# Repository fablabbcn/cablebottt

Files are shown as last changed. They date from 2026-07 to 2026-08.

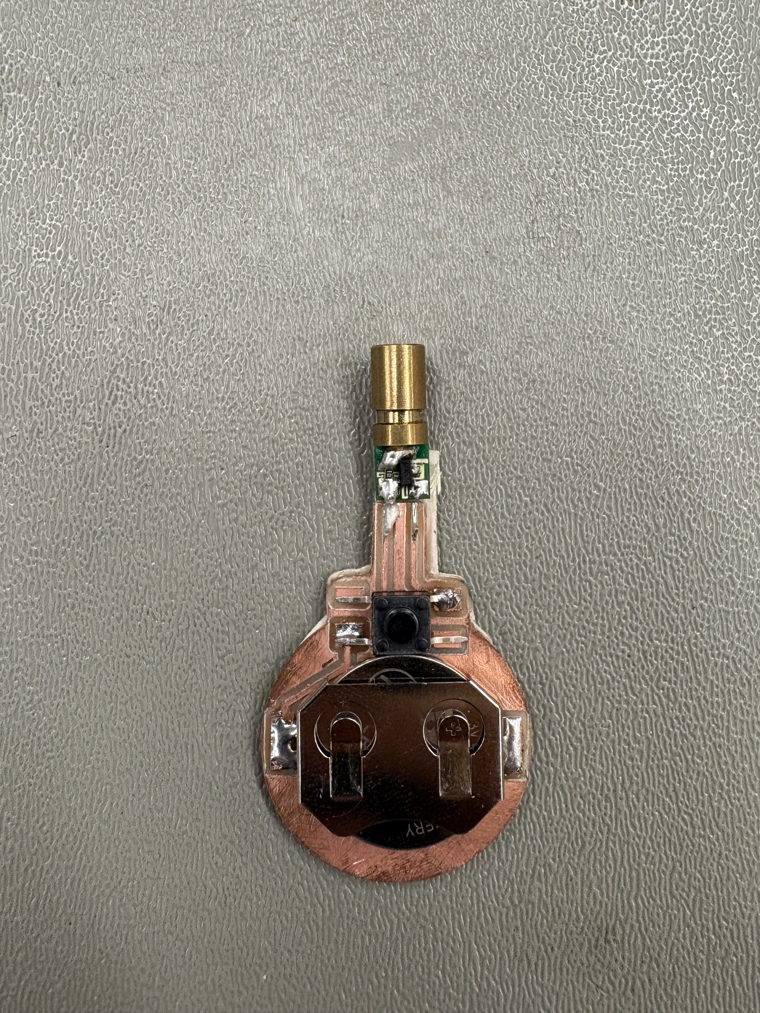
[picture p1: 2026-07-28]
images/puntero_02.jpg

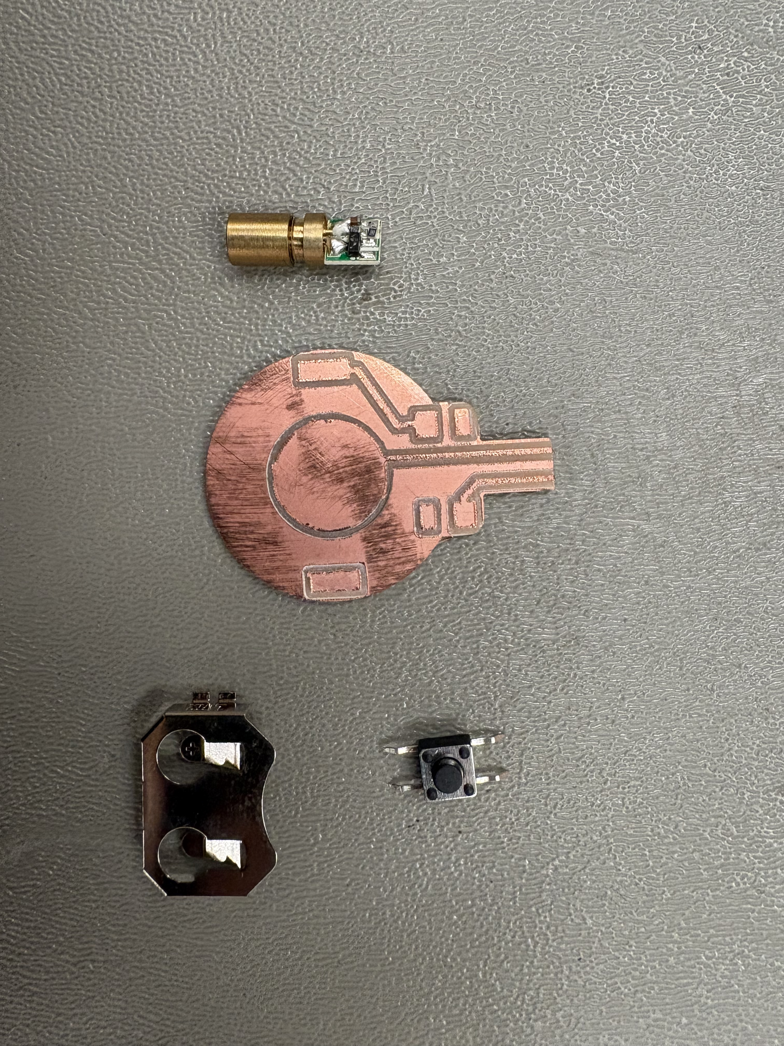
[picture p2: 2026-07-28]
images/puntero_01.jpg

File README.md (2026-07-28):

# CABLEBOTTT

**A hands-on STEAM workshop by FLU @ Fab Lab Barcelona.**

Design, fabricate and program a **cable-driven robot** (cablebot). Participants build a small robot that travels along a cable using a rotating motor, and bring it to life by wiring up inputs (light, distance) and outputs (motor, LED, buzzer, servo). The activity combines **mechanics + digital fabrication + computational thinking** in an accessible, creative format.

> Based on a yellow gearmotor driven from a **Seeed Studio XIAO ESP32-C3**, on a custom PCB.

---

## What you'll build

The cablebot comes in **two behaviors**, using the same hardware:

| | **Sketch A — autonomous** | **Sketch B — teleoperated** |
|---|---|---|
| **Idea** | The robot decides for itself | You drive it from your phone |
| **How** | Follows light using 2 LDR sensors | Serves a webapp over its own WiFi |
| **Inputs** | 2 light sensors (LDR) | Distance sensor (optional) |
| **Outputs** | Motor | Motor, color LED, buzzer, servo |
| **Libraries** | None | Adafruit NeoPixel + VL53L1X |
| **Best for** | Seeing a closed feedback loop | Programming your own behaviors |

Both are fully documented — see **[Programming](#3-programming)** below.

---

## Folder structure

```
cablebottt/
├── README.md                        ← you are here (project index)
│
├── fabrication/                     ← everything you cut / print / mill
│   ├── ⟨laser_pieces.svg⟩           ← laser-cut structure (the 3 assembly pieces)
│   ├── ⟨mount_3d.stl⟩               ← 3D-printed parts (if any)
│   ├── pcb/                         ← custom PCB (KiCad project + Gerbers)
│   │   ├── fab26_cablebot.kicad_pro
│   │   ├── fab26_cablebot.kicad_sch
│   │   ├── fab26_cablebot.kicad_pcb
│   │   ├── gerber/                  ← ready-to-mill / ready-to-order
│   │   └── svg/fab26_cablebot-preview.svg
│   └── silkscreen/back_silkscreen.svg
│
├── code/
│   ├── cablebottt_laser/cablebottt.ino        ← Sketch A (autonomous)
│   └── cablebottt_web/cablebottt_web.ino      ← Sketch B (teleoperated)
│
├── docs/
│   ├── cablebottt_sketch_A_tutorial.md        ← how to program Sketch A
│   └── cablebottt_sketch_B_tutorial.md        ← how to program Sketch B
│
└── images/                          ← photos & reference
    ├── ⟨assembled_bot.jpg⟩
    ├── ⟨soldering_xiao.jpg⟩
    └── ⟨pcb_render.png⟩
```

> **⟨…⟩ = placeholder.** Replace with your real filenames. If the layout above doesn't match how you organized the folder, adjust the paths — the section links below still work as long as the two `docs/…` tutorials keep their names.

---

## How to use this project

Do it in three stages. Each stage has its own detailed doc; this index just tells you the order.

### 1. Fabricate

| Part | File | Process |
|---|---|---|
| Structure | `fabrication/⟨laser_pieces.svg⟩` | Laser-cut, then assemble the 3 pieces |
| Custom PCB | `fabrication/pcb/gerber/` | Mill or order from the Gerbers |
| Board | Seeed Studio **XIAO ESP32-C3** | Solder the header pins onto the PCB |

Populate the PCB, solder the XIAO, attach the motor and the laser pointer, and assemble the laser-cut structure. Photos in **`images/`**.

### 2. Wire it up

The XIAO pinout, shared across both sketches:

| Function | Pin | Used by |
|---|---|---|
| Motor driver 1 / 2 | `D9` / `D10` | both |
| LDR left / right | `A1` / `A0` | Sketch A |
| NeoPixel (LED) | `D7` | Sketch B |
| Buzzer | `D6` | Sketch B |
| Servo | `D8` | Sketch B |
| Distance sensor SDA / SCL | `D4` / `D5` | Sketch B |

### 3. Programming

Pick the behavior and follow its step-by-step tutorial:

- **Autonomous (follows light)** → **[`docs/cablebottt_sketch_A_tutorial.md`](docs/cablebottt_sketch_A_tutorial.md)**
  *No libraries needed. Upload and go.*
- **Teleoperated (phone webapp)** → **[`docs/cablebottt_sketch_B_tutorial.md`](docs/cablebottt_sketch_B_tutorial.md)**
  *Install 2 libraries, then connect your phone to the `CABLEBOTTT` WiFi network.*

Both tutorials cover the one-time Arduino IDE + ESP32-C3 setup, so you only need to read it once.

---

## Quick start (already fabricated & flashed?)

1. Power the board over USB-C or the 9V battery.
2. **Sketch A:** shine a light near an LDR — the robot follows it.
3. **Sketch B:** on your phone, join WiFi **`CABLEBOTTT`** (password `cablebottt`), open **`http://192.168.4.1`**, and drive it.

---

*Originally created for a **FAB26 Boston** workshop. Repo: `github.com/fablabbcn/cablebottt`.*

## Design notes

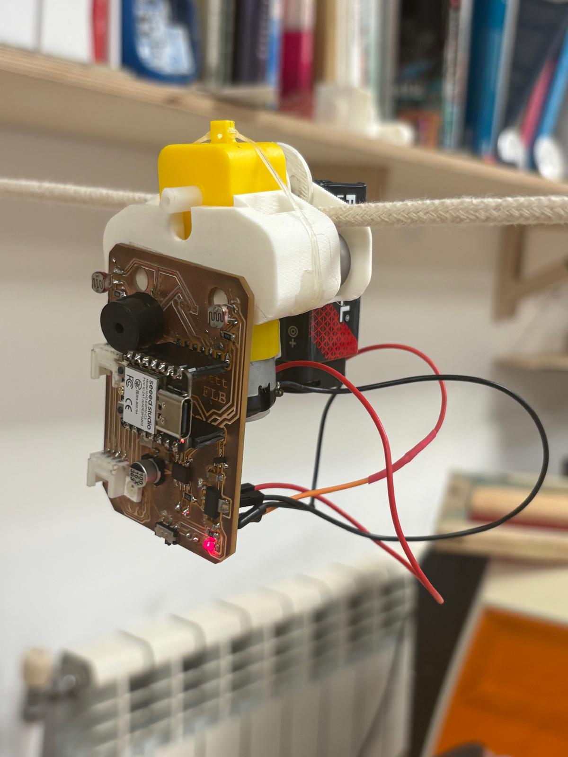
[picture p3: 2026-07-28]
images/Cable bot.jpeg

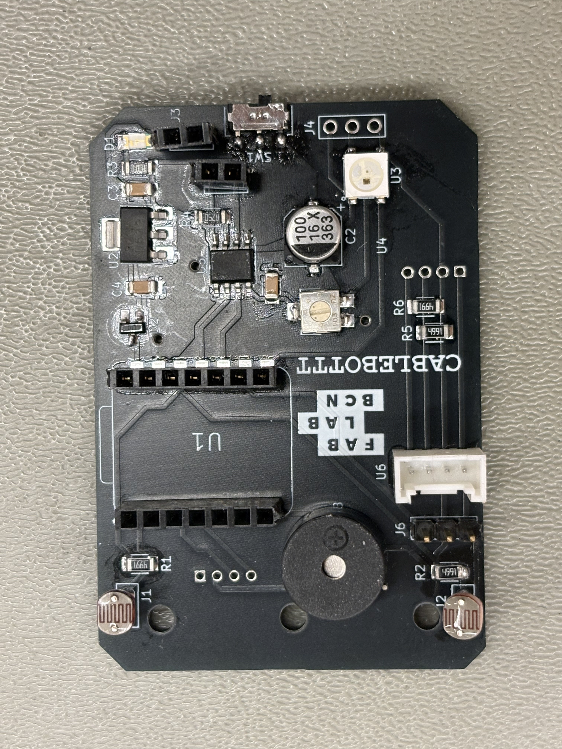
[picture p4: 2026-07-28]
images/board.jpg

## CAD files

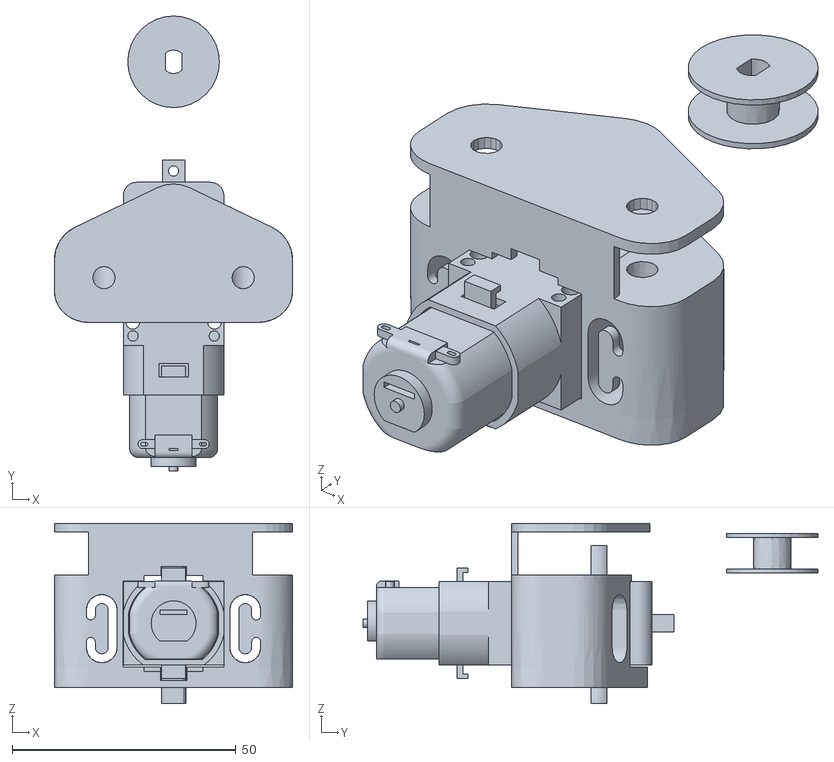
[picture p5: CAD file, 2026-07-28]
3d_design/rodamiento v3_R7.stl
53.2 x 101.6 x 40.2

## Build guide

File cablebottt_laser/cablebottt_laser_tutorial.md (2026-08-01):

# CABLEBOTTT — Sketch A: `cablebottt_laser`

**Autonomous light-following robot.** The cablebot reads two light-dependent resistors, or LDRs, and drives its motor towards the side receiving more light. It demonstrates a simple **sensor → decision → actuator** loop.

**Board:** Seeed Studio XIAO ESP32-C3
**File:** `cablebottt_laser/cablebottt.ino`
**Repository:** `github.com/fablabbcn/cablebottt`

---

## 📚 Libraries needed: none

This sketch does not use any external libraries. It relies only on functions included in the standard Arduino core for ESP32, including:

* `Serial`
* `analogRead`
* `analogWrite`
* `digitalWrite`
* `pinMode`
* `millis`
* `delay`

Once the ESP32 board package is installed, you can compile and upload the sketch directly. No additional installation through the Library Manager is required.

---

## Part 1 — One-time setup

You only need to complete this section once on each computer.

### 1.1 · Install the Arduino IDE

Download and install the stable version of **Arduino IDE 2.x** from:

`arduino.cc/en/software`

### 1.2 · Add ESP32 board support

1. Open **File › Preferences**. On macOS, open **Arduino IDE › Settings**.

2. Find **Additional Boards Manager URLs**.

3. Add:

   ```text
   https://espressif.github.io/arduino-esp32/package_esp32_index.json
   ```

4. Press **OK**.

### 1.3 · Install the ESP32 boards package

1. Open **Tools › Board › Boards Manager**, or select the boards icon in the left sidebar.
2. Search for `esp32`.
3. Install **esp32 by Espressif Systems**.

Installation may take a few minutes.

### 1.4 · Select the board and port

1. Connect the XIAO using a **USB-C data cable**. Some USB cables provide power but do not transfer data.
2. Select **Tools › Board › esp32 › XIAO_ESP32C3**.
3. Open **Tools › Port** and select the port that appears when the board is connected.

Typical port names are:

* Windows: `COM3`, `COM4`, etc.
* macOS: `/dev/cu.usbmodem…`
* Linux: `/dev/ttyACM0` or similar

### 1.5 · Enable USB serial output

Under **Tools**, set:

```text
USB CDC On Boot → Enabled
```

Without this setting, the Serial Monitor may remain blank when using the XIAO ESP32-C3 over USB-C.

Leave the other board options at their default values unless your setup requires otherwise.

---

## Part 2 — Upload Sketch A

### 2.1 · Open the sketch

Open:

```text
cablebottt_laser/cablebottt.ino
```

You can double-click the `.ino` file or use **File › Open** in the Arduino IDE.

### 2.2 · Check the board and port

Confirm that:

* the selected board is `XIAO_ESP32C3`;
* the correct serial port is selected.

### 2.3 · Upload

Press the **Upload** button.

The Arduino IDE will compile the sketch and write it to the board. A message such as:

```text
Hard resetting via RTS pin...
```

normally indicates that the upload completed successfully.

### 2.4 · Test the robot

1. Open **Tools › Serial Monitor**.
2. Set the baud rate to `115200`.
3. Restart the board.
4. Keep the laser or flashlight away from both sensors while the robot calibrates.
5. Shine light onto one LDR.

The motor should move towards the side receiving the stronger light.

Calibration takes approximately 1.5 seconds after startup. The robot should remain still during this period.

---

## How the sketch works

| Step | What happens |
| --- | --- |
| **Stabilise** | The sketch waits briefly after startup so the power supply and analogue readings can settle. |
| **Calibrate** | It averages 25 readings from each LDR to establish the ambient-light baseline. |
| **Read** | It continuously reads both sensors and calculates a moving average from the latest five samples. |
| **Measure change** | It compares each filtered reading with its startup baseline. In this circuit, more light produces a lower analogue value. |
| **Ignore noise** | Small changes are ignored using an activation threshold. Similar readings on both sides are ignored using a deadband. |
| **Decide** | The sketch identifies which LDR is receiving the stronger increase in light. |
| **Act** | It drives the motor towards that side. A larger difference between the sensors produces a higher motor speed. |
| **Stop** | The motor stops when there is no strong light signal or when both sensors receive similar amounts of light. |

This creates a basic **closed feedback loop**: the robot senses its environment, evaluates the information and changes its movement in response.

---

## Key parameters

The behaviour can be adjusted near the beginning of the sketch:

```cpp
#define FILTER_SAMPLES 5
#define CALIBRATION_SAMPLES 25

const int ACTIVATION_THRESHOLD = 200;
const int DIFFERENCE_DEADBAND = 80;
const int MIN_MOTOR_SPEED = 70;
```

### `FILTER_SAMPLES`

Controls how many recent readings are averaged.

* Higher values produce smoother readings.
* Lower values respond more quickly.

### `CALIBRATION_SAMPLES`

Controls how many readings are used to establish the ambient-light baseline.

A higher value produces a more stable calibration, but takes slightly longer.

### `ACTIVATION_THRESHOLD`

Sets how large the change from ambient light must be before the robot reacts.

Increase this value if the robot reacts to normal room-light variation.

### `DIFFERENCE_DEADBAND`

Sets how different the two sensors must be before the motor chooses a direction.

Increase this value if the robot oscillates when both sensors receive similar light.

### `MIN_MOTOR_SPEED`

Sets the minimum PWM value used once movement is activated.

This helps ensure that the motor receives enough power to start moving rather than humming or remaining stalled.

---

## Pinout

| Function | Pin |
| --- | ----- |
| Motor driver input 1 | `D9`  |
| Motor driver input 2 | `D10` |
| Left LDR | `A1`  |
| Right LDR | `A0`  |
| Buzzer, currently inactive | `D6`  |

---

## Quick troubleshooting

| Symptom | Likely cause | Fix |
| --- | --- | --- |
| The board does not appear under **Port** | Charge-only USB cable or board not entering upload mode | Try another USB-C cable. To enter bootloader mode, hold **BOOT**, press and release **RESET**, then release **BOOT**. |
| Serial Monitor is blank | USB CDC is disabled or the wrong baud rate is selected | Set **USB CDC On Boot → Enabled**, upload again and select `115200` baud. |
| `Failed to connect` during upload | Incorrect port, port in use or board not in bootloader mode | Close the Serial Monitor, confirm the port and retry in bootloader mode. |
| The IDE identifies the board incorrectly | Automatic board detection is unreliable | Manually select `XIAO_ESP32C3` under **Tools › Board**. |
| The motor moves briefly during startup | `D9` is involved in the ESP32-C3 boot configuration | A short movement may occur before the sketch takes control. Hardware pull-downs or a motor-driver enable pin provide a more reliable solution. |
| The motor does not react to light | Signal is below the threshold, sensors are swapped or the room is already very bright | Cover one LDR or shine a focused light onto the other. Check the `A0` and `A1` connections. |
| The motor moves in the wrong direction | Motor wiring or direction labels are reversed | Swap the motor wires or exchange the calls to `driveLeft()` and `driveRight()`. |
| The motor hums but does not move | PWM is too low or the power supply cannot provide enough current | Increase `MIN_MOTOR_SPEED` and check the battery, regulator and motor-driver supply. |
| The robot reacts unpredictably after startup | A sensor was illuminated during calibration | Restart the board with both LDRs exposed only to normal ambient light. |

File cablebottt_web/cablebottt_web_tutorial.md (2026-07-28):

# CABLEBOTTT — Sketch B: `cablebottt_web`

**Phone-controlled robot.** The cablebot creates its own WiFi network and serves a webapp from the board. From your phone you drive the motor and control a color LED, a buzzer, a servo, and an optional distance sensor.

Board: **Seeed Studio XIAO ESP32-C3** · File: **`cablebottt_web/cablebottt_web.ino`** · Repo: `github.com/fablabbcn/cablebottt`

---

## 📚 Libraries needed: 2 (+ 1 automatic)

Unlike Sketch A, this sketch **needs external libraries**. Install these from Library Manager:

| Library | Why |
|---|---|
| **Adafruit NeoPixel** | Drives the color LED (`D7`). |
| **Adafruit VL53L1X** | Drives the time-of-flight distance sensor (`D4`/`D5`). |
| **Adafruit BusIO** | Dependency of VL53L1X — installs **automatically** when you accept "Install All". |

Everything else (`WiFi`, `WebServer`, `Wire`) is already part of the ESP32 core — nothing to add for those.

---

## Part 1 — One-time setup (once per computer)

> If you already set this up for **Sketch A**, skip to **Part 2**. The board setup is identical; only the libraries below are new.

### 1.1 · Install the Arduino IDE
Download the stable **Arduino IDE 2.x** from `arduino.cc/en/software` and install it.

### 1.2 · Add ESP32 board support
1. Go to **File › Preferences** (on Mac: **Arduino IDE › Settings**).
2. In **"Additional boards manager URLs"**, paste:
   ```
   https://espressif.github.io/arduino-esp32/package_esp32_dev_index.json
   ```
3. **OK**.

### 1.3 · Install the boards package
1. **Tools › Board › Boards Manager…** (or the boards icon on the left).
2. Search **`esp32`**.
3. Install **"esp32 by Espressif Systems"** (latest version). Takes a couple of minutes.

### 1.4 · Select board and port
1. Connect the XIAO with a **USB-C data cable** (many cables are charge-only; if the board doesn't show up, swap the cable first).
2. **Tools › Board › esp32 › `XIAO_ESP32C3`**.
3. **Tools › Port** → pick the port that appears when you plug the board in (COMx on Windows, `/dev/cu.usbmodem…` on Mac, `/dev/ttyACM0` on Linux).

### 1.5 · ⚙️ CRITICAL setting for the Serial Monitor
Under **Tools**, set:
- **USB CDC On Boot → `Enabled`**

> Without this, the ESP32-C3's Serial Monitor stays **blank** over USB-C — and you won't see the boot log that tells you the WiFi came up. Turn it on before you start. Leave the other **Tools** options at their defaults.

---

## Part 2 — Install the libraries

Go to **Tools › Manage Libraries…** (or the books icon on the left) and install, one by one:

1. Search **`Adafruit NeoPixel`** → **Install**.
2. Search **`Adafruit VL53L1X`** → **Install**.
   - The IDE will ask whether to also install its **dependencies** (`Adafruit BusIO`). Click **"Install All"**. ✅

That's it — those two (plus BusIO, which comes along) cover everything the sketch imports.

---

## Part 3 — Upload Sketch B

### 3.1 · Open the code
Open **`cablebottt_web/cablebottt_web.ino`**.

### 3.2 · Check board, port and CDC
- Board **`XIAO_ESP32C3`**, correct port.
- **USB CDC On Boot → `Enabled`** (Part 1.5) so you can see the boot log.

### 3.3 · Upload
Press the **Upload** button (→ arrow). It compiles (slower than Sketch A because of the WiFi libraries) and writes.
If it ends with **`Hard resetting via RTS pin…`** → uploaded successfully ✅.

### 3.4 · Verify it works
1. Open **Tools › Serial Monitor** at **`115200 baud`**. You should see the boot sequence:
   ```
   [BOOT] Iniciando cablebottt...
   [BOOT] Motor listo (D9/D10)
   [BOOT] Neopixel listo (D7)
   [BOOT] Servo listo (D8)
   [BOOT] Iniciando WiFi AP...
   [BOOT] SSID: CABLEBOTTT  IP: 192.168.4.1 ...
   [BOOT] Servidor web iniciado
   ```
   The **NeoPixel also runs a self-test**: it blinks red → green → blue. If it doesn't blink, the problem is the library or the LED hardware, not the WiFi.
2. On your **phone**, open WiFi settings and connect to:
   - **Network:** `CABLEBOTTT`
   - **Password:** `cablebottt`
3. Open a browser and go to **`http://192.168.4.1`**
4. The webapp appears. Try each control:
   - **Motor:** press and hold *Left* / *Right* (release to stop).
   - **Neopixel:** turn it on and pick a color.
   - **Buzzer:** play the Mario tune.
   - **Servo:** move the slider.
   - **Distance:** it comes **disabled**; tap it (*Sensor: OFF → ON*) only if you have the VL53L1X connected over I²C (`D4`/`D5`).

---

## How it works (to explain to students)

| Part | What happens |
|---|---|
| **Access Point** | The board doesn't join your WiFi — it *creates* its own network (`CABLEBOTTT`). Your phone connects directly to the robot. |
| **Web server** | The board serves a small webpage. Every button/slider sends a request (e.g. `/motor?dir=left`) that the board acts on. |
| **Outputs** | Motor (`D9`/`D10`), color LED (`D7`), buzzer (`D6`), servo (`D8`) — all driven on command from the page. |
| **Input** | The distance sensor (`D4`/`D5`) is an *input*: when enabled, the board reads it and the page shows the value live. |
| **Safety** | If no command arrives for ~1 second, the motor stops on its own — so a dropped connection can't leave it running. |

The takeaway for STEAM: same motor as Sketch A, but now **the student is in the loop**. They decide what each input and output does — the door to programming their own behaviors.

---

## Pinout (Sketch B)

| Function | Pin |
|---|---|
| Motor driver 1 | `D9` |
| Motor driver 2 | `D10` |
| NeoPixel | `D7` |
| Buzzer | `D6` |
| Servo | `D8` |
| Distance sensor SDA / SCL | `D4` / `D5` |

---

## Quick troubleshooting

| Symptom | Likely cause | Fix |
|---|---|---|
| Compiles but a **library is missing** | NeoPixel / VL53L1X not installed | Part 2. Remember **"Install All"** so BusIO comes in too. |
| Board **doesn't appear** under Port | Charge-only cable, or board stuck | Swap the USB-C cable. If it persists: **bootloader mode** → hold **BOOT**, press and release **RESET**, release **BOOT**. The port reappears; upload again. |
| **Serial Monitor blank** | CDC missing | **Tools › USB CDC On Boot → Enabled** and upload again. |
| `A fatal error occurred: Failed to connect` | Port busy or in run mode | Close the Serial Monitor, enter bootloader mode (BOOT+RESET) and retry. |
| IDE shows **DFRobot Beetle** on connect | Known auto-detection bug | Ignore it: manually select `XIAO_ESP32C3` under **Tools › Board** and upload anyway. |
| Can't see the `CABLEBOTTT` network | The AP didn't come up | Check the Serial: if it says `softAP() devolvió FALLO`, reset the board. Move away from crowded WiFi areas. |
| Connected to WiFi but page **won't load** | Wrong address | Type the full `http://192.168.4.1` (some phones auto-search instead of browsing). Disable mobile data so the phone uses the robot's network. |
| **NeoPixel** doesn't do the red/green/blue self-test | Library or LED wiring | Reinstall Adafruit NeoPixel; check the `D7` connection. It's independent of the WiFi. |
| **Motor spins by itself** for an instant on boot | Pin `D9` is a *strapping* pin (boots high) | Normal. The code forces it LOW as soon as it starts. |
| **Distance** shows *"Sensor no conectado"* | Sensor missing or I²C wiring | Only enable it if the VL53L1X is wired to `D4`/`D5`. Otherwise leave it OFF. |

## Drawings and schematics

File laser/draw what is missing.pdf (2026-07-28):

# Draw what is missing!

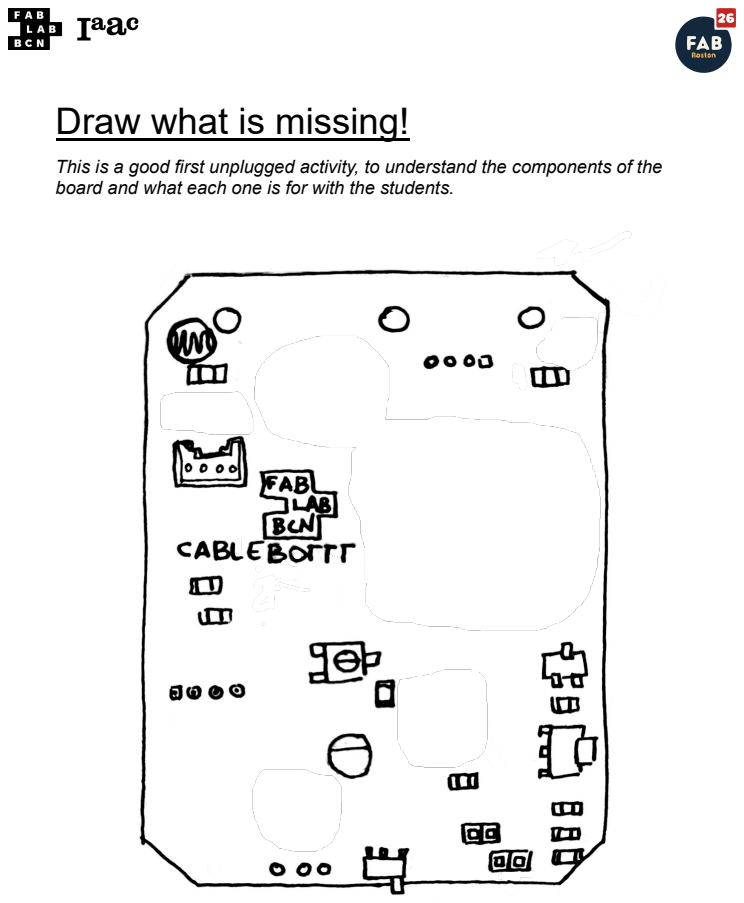
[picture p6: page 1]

This is a good first unplugged activity, to understand the components of the
board and what each one is for with the students.

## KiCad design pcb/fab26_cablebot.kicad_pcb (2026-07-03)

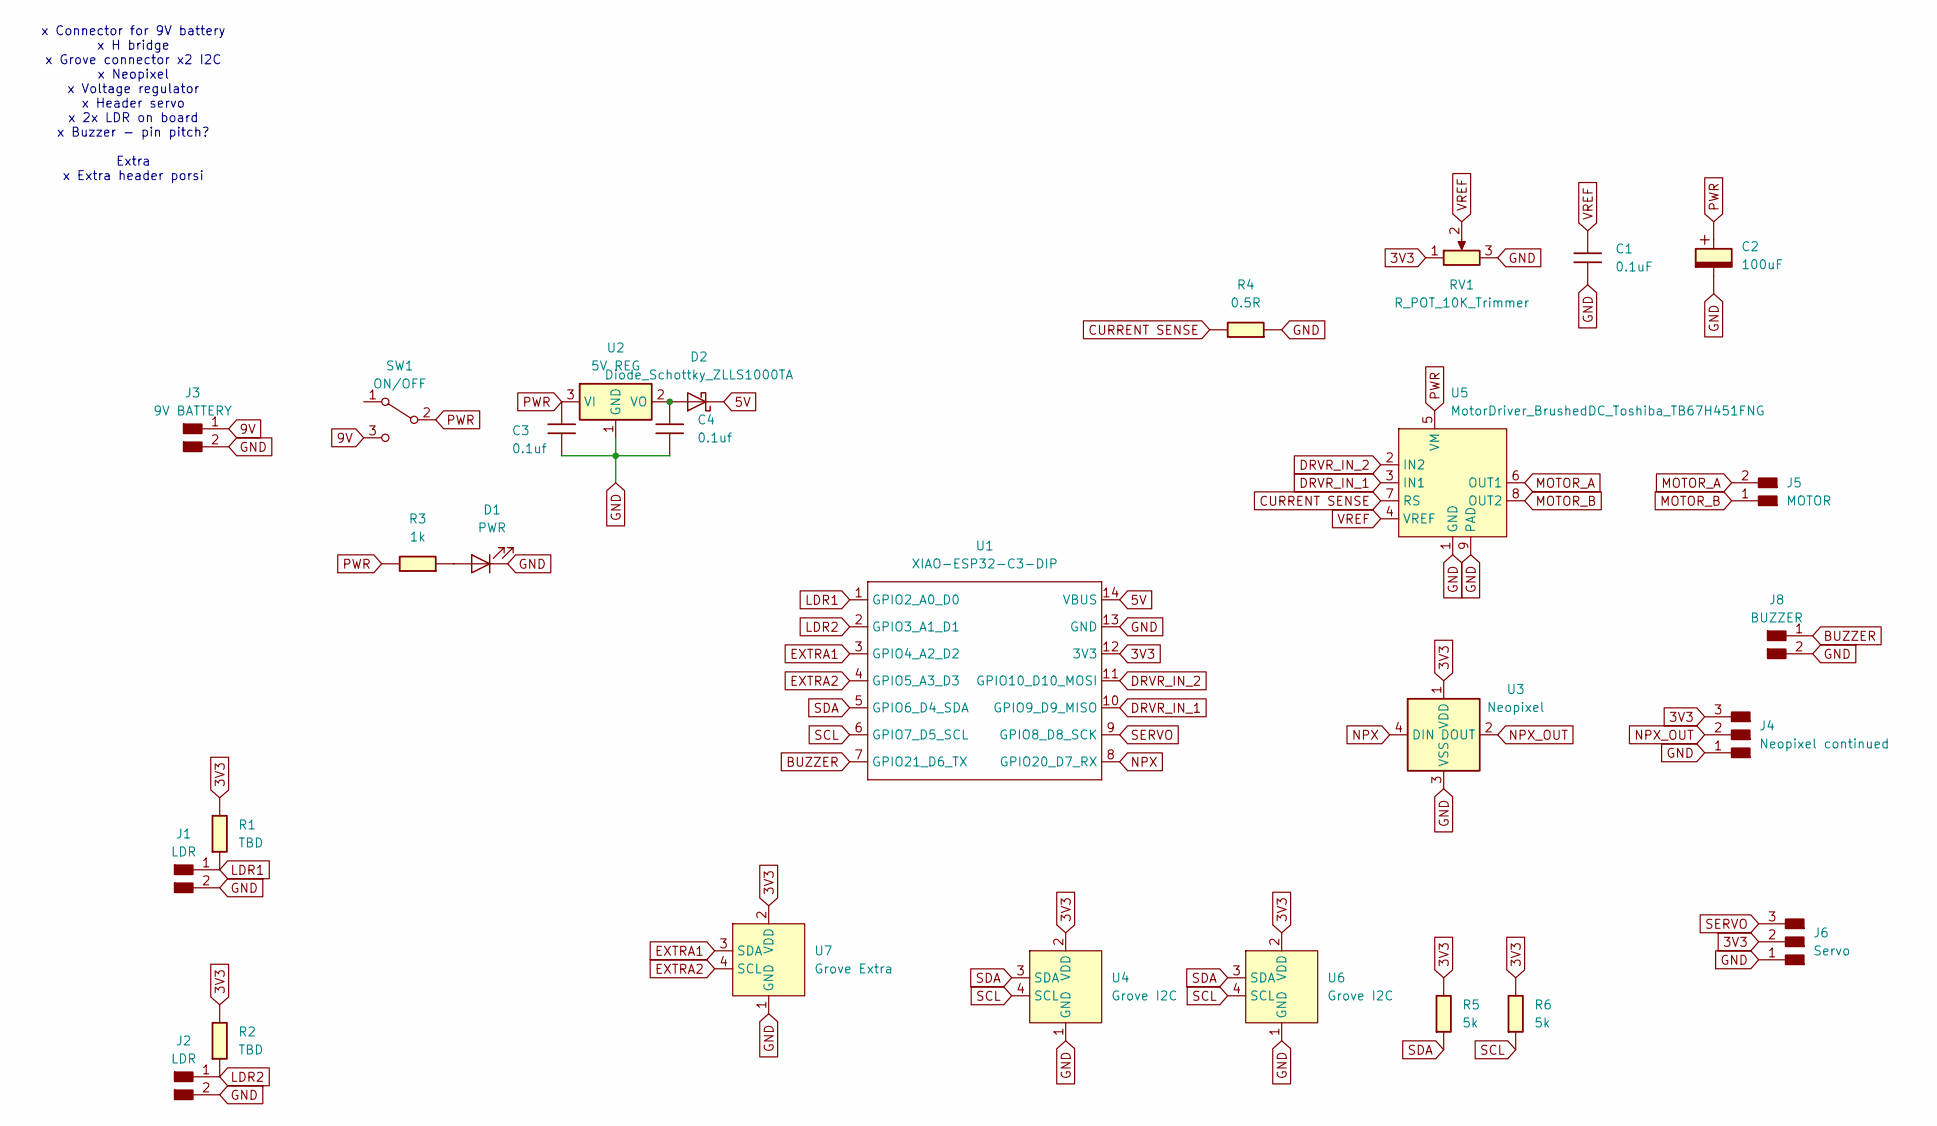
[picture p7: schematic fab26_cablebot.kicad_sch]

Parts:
C1: 0.1uF; C_1206
C2: 100uF; CP_Elec_100uF_Panasonic_EEE-FN1E101UL
C3, C4: 0.1uf; C_1206
D1: PWR; LED_1206
D2: Diode_Schottky_ZLLS1000TA; SOT-23
J1, J2: LDR; PinHeader_01x02_P2.54mm_Vertical_THT_D1mm
J3: 9V BATTERY; PinHeader_01x02_P2.54mm_Vertical_THT_D1mm
J4: Neopixel continued; PinHeader_01x03_P2.54mm_Vertical_THT_D1mm
J5: MOTOR; PinHeader_01x02_P2.54mm_Vertical_THT_D1mm
J6: Servo; PinHeader_01x03_P2.54mm_Vertical_THT_D1mm
J8: BUZZER; PinHeader_01x02_P2.54mm_Vertical_THT_D1mm
R1, R2: TBD; R_1206
R3: 1k; R_1206
R4: 0.5R; R_1206
R5, R6: 5k; R_1206
RV1: R_POT_10K_Trimmer; Potentiometer_TT_Model-23_4.5x5.0x3.0mm
SW1: ON/OFF; Switch_Slide_RightAngle_CnK_AYZ0102AGRLC_7.2x3mm
U1: XIAO-ESP32-C3-DIP
U2: 5V REG; SOT-223-3_TabPin2
U3: Neopixel; LED_ADDR_Worldsemi_WS2812B
U4, U6: Grove I2C; GROVE-HW4-2.0-90D
U5: MotorDriver_BrushedDC_Toshiba_TB67H451FNG; HSOP-8
U7: Grove Extra; GROVE-HW4-2.0-90D

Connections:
3V3: J4.3, J6.2, R1.1, R2.1, R5.1, R6.1, RV1.1, U1.12 (3V3), U3.1 (VDD), U4.2 (VDD), U6.2 (VDD), U7.2 (VDD)
5V: D2.3 (K), U1.14 (VBUS)
9V: J3.1, SW1.3 (C)
BUZZER: J8.1, U1.7 (GPIO21_D6_TX)
CURRENT SENSE: R4.1, U5.7 (RS)
DRVR_IN_1: U1.10 (GPIO9_D9_MISO), U5.3 (IN1)
DRVR_IN_2: U1.11 (GPIO10_D10_MOSI), U5.2 (IN2)
EXTRA1: U1.3 (GPIO4_A2_D2), U7.3 (SDA)
EXTRA2: U1.4 (GPIO5_A3_D3), U7.4 (SCL)
GND: C1.2, C2.2, C3.2, C4.2, D1.1 (K), J1.2, J2.2, J3.2, J4.1, J6.1, J8.2, R4.2, RV1.3, U1.13 (GND), U2.1 (GND), U3.3 (VSS), U4.1 (GND), U5.1 (GND), U5.9 (PAD), U6.1 (GND), U7.1 (GND)
LDR1: J1.1, R1.2, U1.1 (GPIO2_A0_D0)
LDR2: J2.1, R2.2, U1.2 (GPIO3_A1_D1)
MOTOR_A: J5.2, U5.6 (OUT1)
MOTOR_B: J5.1, U5.8 (OUT2)
NPX: U1.8 (GPIO20_D7_RX), U3.4 (DIN)
NPX_OUT: J4.2, U3.2 (DOUT)
unnamed: D1.2 (A), R3.2
unnamed: C4.1, D2.1 (A), U2.2 (VO)
PWR: C2.1, C3.1, R3.1, SW1.2 (B), U2.3 (VI), U5.5 (VM)
SCL: R6.2, U1.6 (GPIO7_D5_SCL), U4.4 (SCL), U6.4 (SCL)
SDA: R5.2, U1.5 (GPIO6_D4_SDA), U4.3 (SDA), U6.3 (SDA)
SERVO: J6.3, U1.9 (GPIO8_D8_SCK)
VREF: C1.1, RV1.2, U5.4 (VREF)

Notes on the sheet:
x Connector for 9V battery x H bridge x Grove connector x2 I2C x Neopixel x Voltage regulator x Header servo x 2x LDR on board x Buzzer - pin pitch? Extra x Extra header porsi

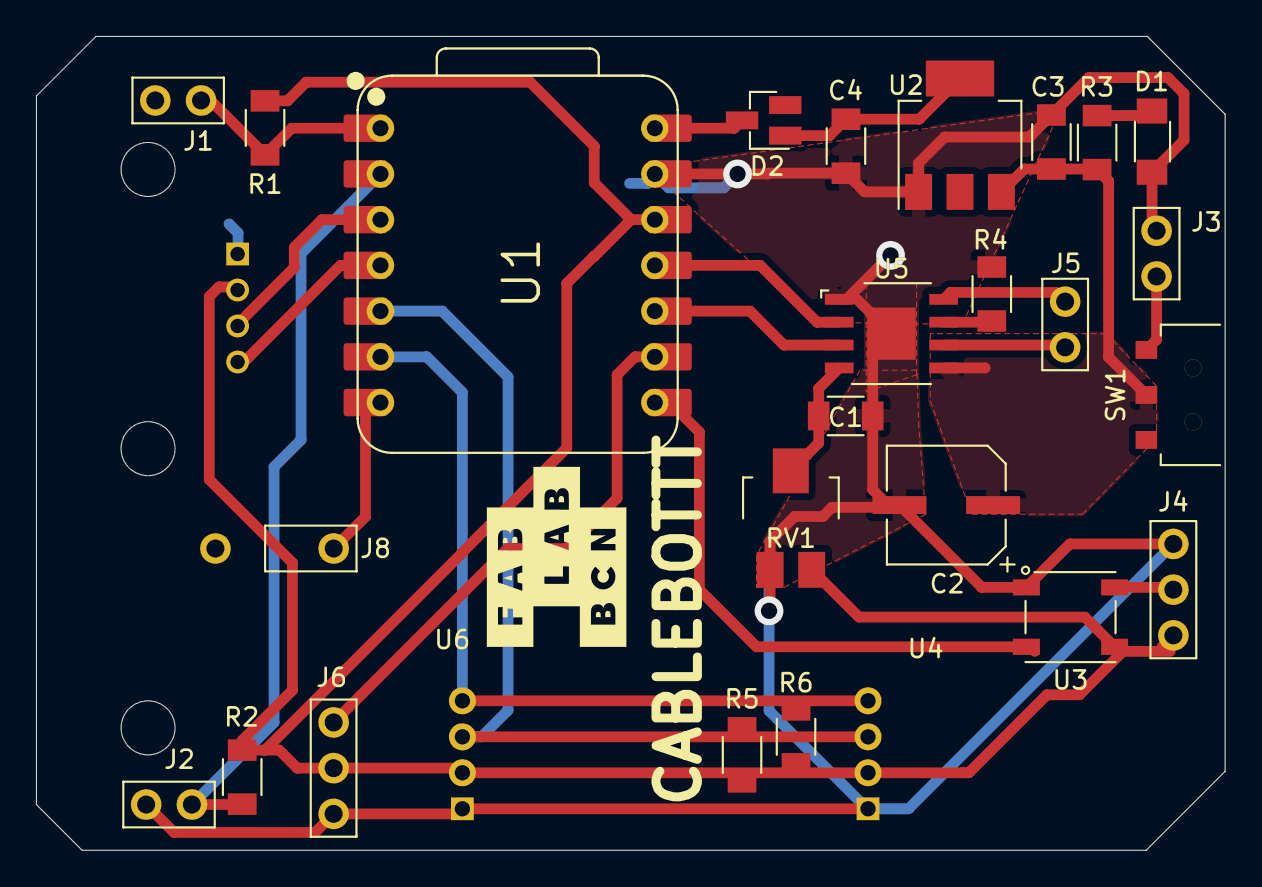
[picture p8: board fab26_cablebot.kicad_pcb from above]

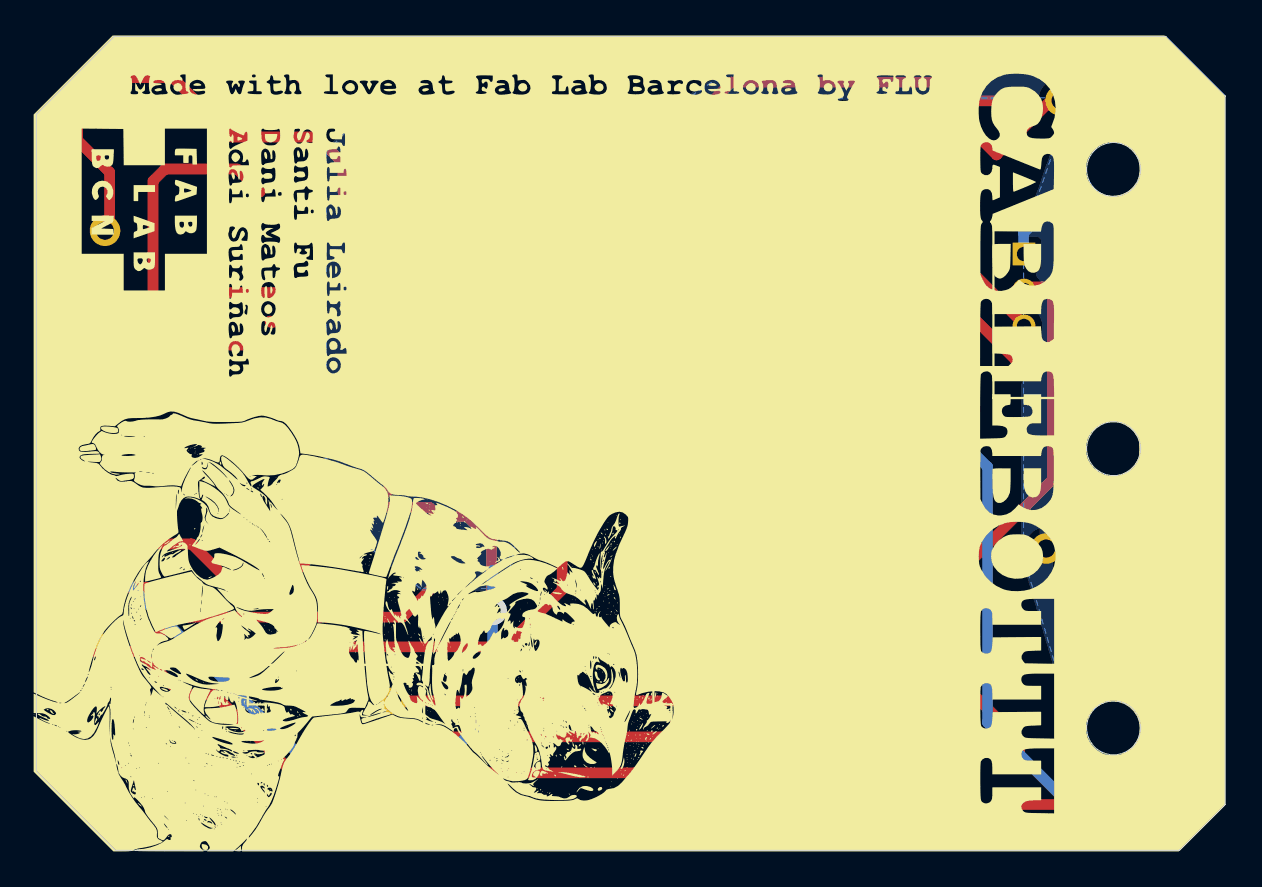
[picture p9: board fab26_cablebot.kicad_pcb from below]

Board: 2 copper layers, 66.0 x 45.2 mm, 28 parts (3 on the bottom side), 23 nets.

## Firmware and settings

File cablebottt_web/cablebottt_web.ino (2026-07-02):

// Librerias necesarias (Arduino Library Manager): Adafruit NeoPixel, Adafruit VL53L1X
// (el servo se controla por LEDC directo, ya no hace falta ESP32Servo)

#include <WiFi.h>
#include <WebServer.h>
#include <Wire.h>
#include <Adafruit_NeoPixel.h>
#include <Adafruit_VL53L1X.h>

#define LDR1_PIN D0
#define LDR2_PIN D1
#define NEOPIXEL_PIN D7
#define MOTOR_PIN1 D10
#define MOTOR_PIN2 D9
#define BUZZER_PIN D6
#define I2C_SDA_PIN D4
#define I2C_SCL_PIN D5
#define SERVO_PIN D8

#define NUM_PIXELS 1
#define MOTOR_STRENGTH 200

const char *AP_SSID = "CABLEBOTTT";
const char *AP_PASSWORD = "cablebottt";

WebServer server(80);
Adafruit_NeoPixel pixel(NUM_PIXELS, NEOPIXEL_PIN, NEO_GRB + NEO_KHZ800);
Adafruit_VL53L1X distanceSensor;

// PWM por canales LEDC EXPLICITOS para que motor y servo nunca compartan canal/timer.
// En el ESP32-C3 los canales se agrupan por timer de dos en dos (ch0-1 -> timer0,
// ch2-3 -> timer1, ch4-5 -> timer2). Ponemos los motores en el timer0 y el servo en el
// timer2, bien separados, y dejamos el timer1 libre para el tone() del zumbador.
#define MOTOR1_LEDC_CH 0
#define MOTOR2_LEDC_CH 1
#define SERVO_LEDC_CH 4
#define MOTOR_PWM_FREQ 20000  // 20 kHz: por encima del rango audible, sin pitido en el motor
#define MOTOR_PWM_RES 8       // duty 0-255

// Parametros del servo
#define SERVO_FREQ 50
#define SERVO_RES_BITS 14
#define SERVO_MIN_US 500
#define SERVO_MAX_US 2400
#define SERVO_PERIOD_US 20000

bool distanceSensorOK = false;
unsigned long lastDistanceAttempt = 0;
const unsigned long DISTANCE_RETRY_INTERVAL_MS = 5000;
int16_t lastDistanceMM = -1;

int motorDir = 0;  // -1 izquierda, 0 parado, 1 derecha
unsigned long lastMotorCommandTime = 0;
const unsigned long MOTOR_TIMEOUT_MS = 900;  // para el motor si no llega otro comando/latido a tiempo

bool distanceSensorEnabled = false;  // el sensor no viene conectado de serie: se activa desde la webapp

bool pixelOn = false;
uint8_t pixelR = 127, pixelG = 119, pixelB = 221;

int servoAngle = 90;

struct Note {
  int freq;
  int dur;
};
const Note marioTune[] = {
  { 660, 150 }, { 660, 150 }, { 0, 150 }, { 660, 150 }, { 0, 150 }, { 523, 150 }, { 660, 150 }, { 0, 150 }, { 784, 150 }, { 0, 450 }, { 392, 150 }
};
const int MARIO_TUNE_LENGTH = sizeof(marioTune) / sizeof(Note);
int marioIndex = -1;  // -1 = no esta sonando
unsigned long marioNoteStart = 0;

const char INDEX_HTML[] = R"rawliteral(
<!DOCTYPE html>
<html lang="es">
<head>
<meta charset="utf-8">
<meta name="viewport" content="width=device-width, initial-scale=1">
<title>cablebottt</title>
<style>
  body { font-family: -apple-system, sans-serif; background:#1c1c1e; color:#f2f2f2; margin:0; padding:16px; }
  h1 { font-size:18px; text-align:center; font-weight:500; margin:0 0 16px; }
  .card { background:#2c2c2e; border-radius:12px; padding:16px; margin-bottom:12px; }
  .label { font-size:13px; color:#9a9a9d; margin:0 0 10px; font-weight:500; }
  .row { display:grid; grid-template-columns:1fr 1fr; gap:10px; }
  button { font-size:14px; color:#f2f2f2; background:#3a3a3c; border:1px solid #48484a; border-radius:8px; padding:0; }
  .motor-btn { height:64px; touch-action:none; user-select:none; -webkit-user-select:none; -webkit-touch-callout:none; -webkit-tap-highlight-color:transparent; }
  .motor-btn.active { background:#0a84ff; }
  .full-btn { width:100%; height:44px; }
  .hint { font-size:11px; color:#77777a; text-align:center; margin:8px 0 0; }
  .pixel-header { display:flex; align-items:center; justify-content:space-between; margin-bottom:10px; }
  .pixel-header button { height:32px; padding:0 14px; }
  .color-row { display:flex; align-items:center; gap:10px; }
  input[type=color] { width:44px; height:36px; padding:2px; border:none; border-radius:8px; background:none; }
  .preview { flex:1; height:36px; border-radius:8px; border:1px solid #48484a; }
  .servo-header { display:flex; align-items:center; justify-content:space-between; margin-bottom:6px; }
  input[type=range] { width:100%; }
  .status-card { display:flex; align-items:center; justify-content:space-between; }
  .status-value { font-size:22px; font-weight:500; margin:4px 0 0; }
</style>
</head>
<body>
<h1>cablebottt</h1>

<div class="card">
  <p class="label">Motor</p>
  <div class="row">
    <button class="motor-btn" id="btnL">Izquierda</button>
    <button class="motor-btn" id="btnR">Derecha</button>
  </div>
  <p class="hint">Manten pulsado para mover, suelta para parar</p>
</div>

<div class="card">
  <div class="pixel-header">
    <p class="label" style="margin:0">Neopixel</p>
    <button id="pixelToggle">Encender</button>
  </div>
  <div class="color-row">
    <input type="color" id="pixelColor" value="#7f77dd">
    <div class="preview" id="pixelPreview" style="background:#7f77dd"></div>
  </div>
</div>

<div class="card">
  <p class="label">Zumbador</p>
  <button class="full-btn" id="btnBuzz">Reproducir melodia Mario</button>
</div>

<div class="card">
  <div class="servo-header">
    <p class="label" style="margin:0">Servo</p>
    <span id="servoOut">90 grados</span>
  </div>
  <input type="range" min="0" max="180" step="1" value="90" id="servoSlider">
</div>

<div class="card status-card">
  <div>
    <p class="label" style="margin:0">Distancia</p>
    <p class="status-value" id="distVal">--</p>
  </div>
  <button id="distToggle" data-on="0">Sensor: OFF</button>
</div>

<script>
let motorAbort = null;
function sendMotorCmd(dir) {
  if (motorAbort) motorAbort.abort();
  motorAbort = new AbortController();
  fetch('/motor?dir=' + dir, { signal: motorAbort.signal }).catch(() => {});
}
let motorInterval = null;
function startMotor(dir) {
  sendMotorCmd(dir);
  if (motorInterval) clearInterval(motorInterval);
  motorInterval = setInterval(() => sendMotorCmd(dir), 300);
}
function stopMotor() {
  if (motorInterval) { clearInterval(motorInterval); motorInterval = null; }
  sendMotorCmd('stop');
}

function bindMotorButton(el, dir) {
  let active = false;
  const start = (e) => {
    if (e.cancelable) e.preventDefault();  // evita scroll / click sintetico con retardo en movil
    if (active) return;
    active = true;
    el.classList.add('active');
    startMotor(dir);
  };
  const end = () => {
    if (!active) return;
    active = false;
    el.classList.remove('active');
    stopMotor();
  };
  // El "pulsar" se escucha en el boton; el "soltar" se escucha en toda la ventana,
  // asi se captura aunque el dedo se salga del boton antes de levantarlo.
  el.addEventListener('touchstart', start, { passive: false });
  el.addEventListener('mousedown', start);
  window.addEventListener('touchend', end);
  window.addEventListener('touchcancel', end);
  window.addEventListener('mouseup', end);
  window.addEventListener('blur', end);
}
bindMotorButton(document.getElementById('btnL'), 'left');
bindMotorButton(document.getElementById('btnR'), 'right');
document.addEventListener('visibilitychange', () => { if (document.hidden) stopMotor(); });

let pixelOn = false;
let lastPixelInteract = 0;
const pixelToggle = document.getElementById('pixelToggle');
const pixelColor = document.getElementById('pixelColor');
const pixelPreview = document.getElementById('pixelPreview');
function updatePixelLabel() {
  pixelToggle.textContent = pixelOn ? 'Apagar' : 'Encender';
}
function sendPixelState() {
  lastPixelInteract = Date.now();
  fetch('/pixel?on=' + (pixelOn ? '1' : '0') + '&color=' + encodeURIComponent(pixelColor.value.substring(1))).catch(() => {});
}
pixelToggle.addEventListener('click', () => {
  pixelOn = !pixelOn;
  updatePixelLabel();
  sendPixelState();
});
pixelColor.addEventListener('input', () => {
  pixelPreview.style.background = pixelColor.value;
  sendPixelState();
});

document.getElementById('btnBuzz').addEventListener('click', () => fetch('/buzzer'));

const servoSlider = document.getElementById('servoSlider');
const servoOut = document.getElementById('servoOut');
let servoSendTimer = null;
servoSlider.addEventListener('input', () => {
  servoOut.textContent = servoSlider.value + ' grados';
  if (servoSendTimer) clearTimeout(servoSendTimer);
  servoSendTimer = setTimeout(() => fetch('/servo?angle=' + servoSlider.value), 80);
});

const distVal = document.getElementById('distVal');
const distToggle = document.getElementById('distToggle');
distToggle.addEventListener('click', () => {
  const turningOn = distToggle.dataset.on !== '1';
  fetch('/distance/enabled?on=' + (turningOn ? '1' : '0'));
});
function pollStatus() {
  fetch('/status').then(r => r.json()).then(s => {
    // Reconciliar el boton del LED con el estado real del ESP32, salvo que el usuario
    // acabe de tocarlo (para no pisar su accion mientras la peticion esta en vuelo).
    if (Date.now() - lastPixelInteract > 1500 && pixelOn !== s.pixel_on) {
      pixelOn = s.pixel_on;
      updatePixelLabel();
    }
    distToggle.dataset.on = s.distance_enabled ? '1' : '0';
    distToggle.textContent = 'Sensor: ' + (s.distance_enabled ? 'ON' : 'OFF');
    if (!s.distance_enabled) {
      distVal.textContent = 'Desactivado';
    } else {
      distVal.textContent = s.distance_ok ? (s.distance_mm + ' mm') : 'Sensor no conectado';
    }
  }).catch(() => {});
}
setInterval(pollStatus, 1000);
pollStatus();
</script>
</body>
</html>
)rawliteral";

// Helpers de PWM con canal LEDC explicito (API distinta en core 2.x y 3.x).
// Asignar el canal a mano evita que el core reparta canales al azar y que motor y servo
// acaben compartiendo timer (era la causa de que mover el servo activara el motor).
void pwmAttach(uint8_t pin, uint32_t freq, uint8_t res, uint8_t ch) {
#if ESP_ARDUINO_VERSION_MAJOR >= 3
  ledcAttachChannel(pin, freq, res, ch);
#else
  ledcSetup(ch, freq, res);
  ledcAttachPin(pin, ch);
#endif
}

void pwmWrite(uint8_t pin, uint8_t ch, uint32_t duty) {
#if ESP_ARDUINO_VERSION_MAJOR >= 3
  ledcWrite(pin, duty);
#else
  ledcWrite(ch, duty);
#endif
}

void motorSetup() {
  pwmAttach(MOTOR_PIN1, MOTOR_PWM_FREQ, MOTOR_PWM_RES, MOTOR1_LEDC_CH);
  pwmAttach(MOTOR_PIN2, MOTOR_PWM_FREQ, MOTOR_PWM_RES, MOTOR2_LEDC_CH);
  pwmWrite(MOTOR_PIN1, MOTOR1_LEDC_CH, 0);
  pwmWrite(MOTOR_PIN2, MOTOR2_LEDC_CH, 0);
}

void servoSetup() {
  pwmAttach(SERVO_PIN, SERVO_FREQ, SERVO_RES_BITS, SERVO_LEDC_CH);
}

void servoWriteAngle(int angle) {
  angle = constrain(angle, 0, 180);
  uint32_t us = map(angle, 0, 180, SERVO_MIN_US, SERVO_MAX_US);
  uint32_t maxCount = (1UL << SERVO_RES_BITS);
  uint32_t duty = (uint32_t)(((uint64_t)us * maxCount) / SERVO_PERIOD_US);
  pwmWrite(SERVO_PIN, SERVO_LEDC_CH, duty);
}

void setMotor(int dir, int strength) {
  strength = constrain(strength, 0, 255);
  if (dir > 0) {
    pwmWrite(MOTOR_PIN2, MOTOR2_LEDC_CH, 0);
    pwmWrite(MOTOR_PIN1, MOTOR1_LEDC_CH, strength);
  } else if (dir < 0) {
    pwmWrite(MOTOR_PIN1, MOTOR1_LEDC_CH, 0);
    pwmWrite(MOTOR_PIN2, MOTOR2_LEDC_CH, strength);
  } else {
    pwmWrite(MOTOR_PIN1, MOTOR1_LEDC_CH, 0);
    pwmWrite(MOTOR_PIN2, MOTOR2_LEDC_CH, 0);
  }
}

void updateMotorSafety() {
  if (motorDir != 0 && millis() - lastMotorCommandTime > MOTOR_TIMEOUT_MS) {
    motorDir = 0;
    setMotor(0, 0);
  }
}

void pixelSelfTest() {
  const uint32_t testColors[] = { pixel.Color(255, 0, 0), pixel.Color(0, 255, 0), pixel.Color(0, 0, 255) };
  Serial.println("[LED] Autotest: rojo, verde, azul");
  for (int i = 0; i < 3; i++) {
    pixel.setPixelColor(0, testColors[i]);
    pixel.show();
    delay(300);
  }
  pixel.clear();
  pixel.show();
}

// Refresca el LED con el estado actual (sin logs). El WS2812 es "fire and forget": si un
// envio se corrompe por la actividad del WiFi, el LED se queda en un estado erroneo hasta el
// siguiente envio. Rerefrescar periodicamente hace que el color/on-off correcto se reimponga solo.
void refreshPixel() {
  if (pixelOn) {
    pixel.setPixelColor(0, pixel.Color(pixelR, pixelG, pixelB));
  } else {
    pixel.setPixelColor(0, 0);
  }
  pixel.show();
}

void applyPixel() {
  refreshPixel();
  Serial.print("[LED] on=");
  Serial.print(pixelOn);
  Serial.print(" r=");
  Serial.print(pixelR);
  Serial.print(" g=");
  Serial.print(pixelG);
  Serial.print(" b=");
  Serial.println(pixelB);
}

void startMarioNote(int idx) {
  marioIndex = idx;
  marioNoteStart = millis();
  int freq = marioTune[idx].freq;
  if (freq > 0) {
    tone(BUZZER_PIN, freq);
  } else {
    noTone(BUZZER_PIN);
  }
}

void updateMarioTune() {
  if (marioIndex < 0) return;
  if (millis() - marioNoteStart >= (unsigned long)marioTune[marioIndex].dur) {
    int next = marioIndex + 1;
    if (next >= MARIO_TUNE_LENGTH) {
      noTone(BUZZER_PIN);
      marioIndex = -1;
    } else {
      startMarioNote(next);
    }
  }
}

#define VL53L1X_I2C_ADDR 0x29

// El driver del VL53L1X tiene un bucle interno de espera sin limite dentro de begin() (espera a que
// el sensor marque "dato listo", y si no hay sensor eso no ocurre nunca). Por eso comprobamos primero
// con una transaccion I2C basica, que si respeta el timeout del bus, antes de llamar a begin().
bool isDistanceSensorPresent() {
  Wire.beginTransmission(VL53L1X_I2C_ADDR);
  return Wire.endTransmission() == 0;
}

void tryInitDistanceSensor() {
  Serial.println("[I2C] Comprobando presencia del sensor de distancia...");
  lastDistanceAttempt = millis();

  if (!isDistanceSensorPresent()) {
    distanceSensorOK = false;
    Serial.println("[I2C] Sensor no responde en el bus, se reintentara en 5s");
    return;
  }

  Serial.println("[I2C] Sensor presente, inicializando...");
  distanceSensorOK = distanceSensor.begin(VL53L1X_I2C_ADDR, &Wire);
  if (distanceSensorOK) {
    distanceSensor.startRanging();
    distanceSensor.setTimingBudget(50);
    Serial.println("[I2C] Sensor de distancia listo");
  } else {
    Serial.println("[I2C] El sensor respondio en el bus pero begin() fallo, se reintentara en 5s");
  }
}

void updateDistanceSensor() {
  if (!distanceSensorEnabled) return;

  unsigned long now = millis();
  if (!distanceSensorOK) {
    if (now - lastDistanceAttempt > DISTANCE_RETRY_INTERVAL_MS) {
      tryInitDistanceSensor();
    }
    return;
  }

  if (distanceSensor.dataReady()) {
    lastDistanceMM = distanceSensor.distance();
    distanceSensor.clearInterrupt();
  }
}

String pixelColorHex() {
  char buf[8];
  sprintf(buf, "#%02X%02X%02X", pixelR, pixelG, pixelB);
  return String(buf);
}

void handleRoot() {
  server.send(200, "text/html", INDEX_HTML);
}

void handleMotor() {
  if (!server.hasArg("dir")) {
    server.send(400, "text/plain", "falta dir");
    return;
  }
  String dir = server.arg("dir");
  lastMotorCommandTime = millis();
  if (dir == "left") {
    motorDir = -1;
  } else if (dir == "right") {
    motorDir = 1;
  } else {
    motorDir = 0;
  }
  setMotor(motorDir, MOTOR_STRENGTH);
  Serial.print("[MOTOR] dir=");
  Serial.println(dir);
  server.send(200, "text/plain", "ok");
}

void handleDistanceEnabled() {
  if (server.hasArg("on")) {
    distanceSensorEnabled = server.arg("on") == "1";
    Serial.print("[I2C] Sensor de distancia ");
    Serial.println(distanceSensorEnabled ? "activado" : "desactivado");
    if (!distanceSensorEnabled) {
      distanceSensorOK = false;
      lastDistanceMM = -1;
    } else {
      lastDistanceAttempt = 0;  // fuerza un intento de deteccion en el siguiente loop()
    }
  }
  server.send(200, "text/plain", "ok");
}

void handlePixel() {
  if (server.hasArg("on")) pixelOn = server.arg("on") == "1";
  if (server.hasArg("color")) {
    String hex = server.arg("color");
    if (hex.length() == 6) {
      long value = strtol(hex.c_str(), NULL, 16);
      pixelR = (value >> 16) & 0xFF;
      pixelG = (value >> 8) & 0xFF;
      pixelB = value & 0xFF;
    }
  }
  applyPixel();
  server.send(200, "text/plain", "ok");
}

void handleBuzzer() {
  startMarioNote(0);
  server.send(200, "text/plain", "ok");
}

void handleServo() {
  if (server.hasArg("angle")) {
    servoAngle = constrain(server.arg("angle").toInt(), 0, 180);
    servoWriteAngle(servoAngle);
    Serial.print("[SERVO] angulo=");
    Serial.println(servoAngle);
  }
  server.send(200, "text/plain", "ok");
}

void handleStatus() {
  String json = "{";
  json += "\"distance_ok\":" + String(distanceSensorOK ? "true" : "false") + ",";
  json += "\"distance_mm\":" + String(lastDistanceMM) + ",";
  json += "\"servo_angle\":" + String(servoAngle) + ",";
  json += "\"pixel_on\":" + String(pixelOn ? "true" : "false") + ",";
  json += "\"pixel_color\":\"" + pixelColorHex() + "\",";
  json += "\"distance_enabled\":" + String(distanceSensorEnabled ? "true" : "false");
  json += "}";
  server.send(200, "application/json", json);
}

void setupRoutes() {
  server.on("/", HTTP_GET, handleRoot);
  server.on("/motor", HTTP_GET, handleMotor);
  server.on("/pixel", HTTP_GET, handlePixel);
  server.on("/buzzer", HTTP_GET, handleBuzzer);
  server.on("/servo", HTTP_GET, handleServo);
  server.on("/status", HTTP_GET, handleStatus);
  server.on("/distance/enabled", HTTP_GET, handleDistanceEnabled);
  server.onNotFound([]() {
    server.send(404, "text/plain", "No encontrado");
  });
}

void setup() {
  // LO PRIMERO de todo: forzar los pines del motor a LOW antes de cualquier otra cosa.
  // En el ESP32-C3, D9 (GPIO9) es pin de strapping con pull-up interno durante el arranque,
  // asi que el driver puede ver "activo" y girar el motor unos segundos hasta que lo silenciamos.
  // Ponerlos a LOW aqui, antes del delay del serie y del WiFi, reduce ese giro al minimo posible.
  pinMode(MOTOR_PIN1, OUTPUT);
  pinMode(MOTOR_PIN2, OUTPUT);
  digitalWrite(MOTOR_PIN1, LOW);
  digitalWrite(MOTOR_PIN2, LOW);

  Serial.begin(115200);
  delay(600);  // margen para que enumere el USB-CDC del ESP32-C3 (motor ya esta en LOW)
  Serial.println();
  Serial.println("[BOOT] Iniciando cablebottt...");

  motorSetup();  // pasa los pines del motor a PWM (canales LEDC fijos) con duty 0
  Serial.println("[BOOT] Motor listo (D9/D10)");

  pixel.begin();
  pixelSelfTest();  // parpadeo rojo/verde/azul: si no se ve, el problema es libreria o hardware, no la webapp
  applyPixel();
  Serial.println("[BOOT] Neopixel listo (D7)");

  servoSetup();
  servoWriteAngle(servoAngle);
  Serial.println("[BOOT] Servo listo (D8)");

  // WiFi y servidor web se levantan ANTES de tocar el sensor I2C, para que el movil
  // pueda conectarse aunque el sensor de distancia tarde en detectarse o no este conectado.
  Serial.println("[BOOT] Iniciando WiFi AP...");
  WiFi.mode(WIFI_AP);                       // fija explicitamente el modo AP antes de arrancar
  delay(100);
  // canal 1, oculto=0, max 4 clientes. Se comprueba el valor de retorno.
  bool apOk = WiFi.softAP(AP_SSID, AP_PASSWORD, 1, 0, 4);
  delay(100);
  WiFi.setTxPower(WIFI_POWER_8_5dBm);       // baja la potencia TX: reduce picos de corriente que tumban la radio
  Serial.print("[BOOT] softAP() devolvio: ");
  Serial.println(apOk ? "OK" : "FALLO");
  Serial.print("[BOOT] SSID: ");
  Serial.print(AP_SSID);
  Serial.print("  IP: ");
  Serial.print(WiFi.softAPIP());
  Serial.print("  MAC: ");
  Serial.print(WiFi.softAPmacAddress());
  Serial.print("  canal: ");
  Serial.println(WiFi.channel());

  setupRoutes();
  server.begin();
  Serial.println("[BOOT] Servidor web iniciado");

  Wire.begin(I2C_SDA_PIN, I2C_SCL_PIN);
  Wire.setTimeOut(50);
  if (distanceSensorEnabled) {
    tryInitDistanceSensor();
  } else {
    Serial.println("[I2C] Sensor de distancia desactivado por defecto, activalo desde la webapp");
  }

  Serial.println("[BOOT] Setup completo, entrando en loop()");
}

unsigned long lastStaReport = 0;
unsigned long lastPixelRefresh = 0;
void loop() {
  server.handleClient();
  updateMotorSafety();
  updateMarioTune();
  updateDistanceSensor();

  // Reimpone el estado del LED cada 500 ms para corregir envios corrompidos por el WiFi.
  if (millis() - lastPixelRefresh > 500) {
    lastPixelRefresh = millis();
    refreshPixel();
  }

  if (millis() - lastStaReport > 10000) {
    lastStaReport = millis();
    Serial.print("[WIFI] clientes conectados: ");
    Serial.println(WiFi.softAPgetStationNum());
  }
}

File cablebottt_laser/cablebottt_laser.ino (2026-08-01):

#define MOTOR_PIN_1 D9
#define MOTOR_PIN_2 D10

#define BUZZER_PIN D6

#define LEFT_LDR_PIN A1
#define RIGHT_LDR_PIN A0

#define FILTER_SAMPLES 5
#define CALIBRATION_SAMPLES 25

const unsigned long SAMPLE_INTERVAL_MS = 10;
const unsigned long PRINT_INTERVAL_MS = 100;

const int ACTIVATION_THRESHOLD = 200;
const int DIFFERENCE_DEADBAND = 80;
const int MIN_MOTOR_SPEED = 70;

int leftBuffer[FILTER_SAMPLES] = {0};
int rightBuffer[FILTER_SAMPLES] = {0};

int leftBaseline = 0;
int rightBaseline = 0;

int leftReading = 0;
int rightReading = 0;

unsigned long sampleCount = 0;
unsigned long lastSampleTime = 0;
unsigned long lastPrintTime = 0;

void setup() {
  pinMode(MOTOR_PIN_1, OUTPUT);
  pinMode(MOTOR_PIN_2, OUTPUT);
  pinMode(BUZZER_PIN, OUTPUT);

  digitalWrite(MOTOR_PIN_1, LOW);
  digitalWrite(MOTOR_PIN_2, LOW);
  digitalWrite(BUZZER_PIN, LOW);

  Serial.begin(115200);

  analogReadResolution(12);

  stopMotor();

  // Let the power supply and sensors stabilise.
  delay(1000);

  calibrateSensors();
  initialiseFilter();
}

void loop() {
  updateSensorReadings();

  if (sampleCount < FILTER_SAMPLES) {
    stopMotor();
    return;
  }

  controlMotor();
}

void controlMotor() {
  // Compare each live reading with its ambient-light baseline.
  // With this LDR circuit, more light produces a lower reading.
  int leftLightIncrease = leftBaseline - leftReading;
  int rightLightIncrease = rightBaseline - rightReading;

  // Ignore changes caused by the environment becoming darker.
  leftLightIncrease = max(leftLightIncrease, 0);
  rightLightIncrease = max(rightLightIncrease, 0);

  // Find the strongest light change detected by either sensor.
  int strongestLightIncrease =
    max(leftLightIncrease, rightLightIncrease);

  // A positive difference means the left sensor sees more light.
  // A negative difference means the right sensor sees more light.
  int lightDifference =
    leftLightIncrease - rightLightIncrease;

  // Stop if neither sensor sees a sufficiently strong light change.
  if (strongestLightIncrease < ACTIVATION_THRESHOLD) {
    stopMotor();
    return;
  }

  // Stop if both sensors see approximately the same amount of light.
  if (abs(lightDifference) < DIFFERENCE_DEADBAND) {
    stopMotor();
    return;
  }

  // A larger difference between the sensors produces a higher speed.
  int motorSpeed = constrain(
    abs(lightDifference) / 8,
    MIN_MOTOR_SPEED,
    255
  );

  // Move towards the sensor receiving the stronger light.
  if (lightDifference > 0) {
    driveLeft(motorSpeed);
  } else {
    driveRight(motorSpeed);
  }
}

void driveLeft(int motorSpeed) {
  analogWrite(MOTOR_PIN_2, 0);
  digitalWrite(MOTOR_PIN_2, LOW);

  analogWrite(MOTOR_PIN_1, motorSpeed);
}

void driveRight(int motorSpeed) {
  analogWrite(MOTOR_PIN_1, 0);
  digitalWrite(MOTOR_PIN_1, LOW);

  analogWrite(MOTOR_PIN_2, motorSpeed);
}

void stopMotor() {
  analogWrite(MOTOR_PIN_1, 0);
  analogWrite(MOTOR_PIN_2, 0);

  digitalWrite(MOTOR_PIN_1, LOW);
  digitalWrite(MOTOR_PIN_2, LOW);
}

void calibrateSensors() {
  long leftTotal = 0;
  long rightTotal = 0;

  stopMotor();

  Serial.println("Calibrating LDR sensors...");

  for (int i = 0; i < CALIBRATION_SAMPLES; i++) {
    leftTotal += analogRead(LEFT_LDR_PIN);
    rightTotal += analogRead(RIGHT_LDR_PIN);

    delay(20);
  }

  leftBaseline = leftTotal / CALIBRATION_SAMPLES;
  rightBaseline = rightTotal / CALIBRATION_SAMPLES;

  leftReading = leftBaseline;
  rightReading = rightBaseline;

  Serial.print("Left baseline: ");
  Serial.println(leftBaseline);

  Serial.print("Right baseline: ");
  Serial.println(rightBaseline);
}

void initialiseFilter() {
  for (int i = 0; i < FILTER_SAMPLES; i++) {
    leftBuffer[i] = leftBaseline;
    rightBuffer[i] = rightBaseline;
  }

  leftReading = leftBaseline;
  rightReading = rightBaseline;

  sampleCount = FILTER_SAMPLES;
  lastSampleTime = millis();
}

void updateSensorReadings() {
  unsigned long now = millis();

  if (now - lastSampleTime < SAMPLE_INTERVAL_MS) {
    return;
  }

  lastSampleTime = now;

  int bufferIndex = sampleCount % FILTER_SAMPLES;

  leftBuffer[bufferIndex] = analogRead(LEFT_LDR_PIN);
  rightBuffer[bufferIndex] = analogRead(RIGHT_LDR_PIN);

  sampleCount++;

  long leftTotal = 0;
  long rightTotal = 0;

  for (int i = 0; i < FILTER_SAMPLES; i++) {
    leftTotal += leftBuffer[i];
    rightTotal += rightBuffer[i];
  }

  leftReading = leftTotal / FILTER_SAMPLES;
  rightReading = rightTotal / FILTER_SAMPLES;

  printSensorReadings();
}

void printSensorReadings() {
  unsigned long now = millis();

  if (now - lastPrintTime < PRINT_INTERVAL_MS) {
    return;
  }

  lastPrintTime = now;

  Serial.print("Left: ");
  Serial.print(leftReading);

  Serial.print("  Right: ");
  Serial.print(rightReading);

  Serial.print("  Left change: ");
  Serial.print(leftBaseline - leftReading);

  Serial.print("  Right change: ");
  Serial.println(rightBaseline - rightReading);
}

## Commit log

2026-06-30 Working motor control
2026-07-01 Add schematic and pcb
    [fab26_cablebot.kicad_pcb, fab26_cablebot.kicad_sch]
2026-07-01 Create README.md for CABLEBOTTT project
    Add initial README with project overview and details.
2026-07-02 Update cable_web
2026-07-03 Finalize production version of PCB
    [fab26_cablebot-B_Cu.gbr, fab26_cablebot-B_Mask.gbr, fab26_cablebot-B_Paste.gbr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]
2026-08-01 Latest workshop code fix
    [cablebottt_laser.ino]
